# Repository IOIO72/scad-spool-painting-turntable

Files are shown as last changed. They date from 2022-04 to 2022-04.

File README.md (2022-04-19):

# scad-spool-painting-turntable
Spool Painting Turntable

**Update** (5 June 2021):

You can print test parts to verify your measurements of the diameters and inner ring height without wasting too much time and filament.

**Major update** (20 May 2021):

I have converted this model into a customizable version. From now on you can adjust the painting turntable to the individual size of your filament spool.

All you have to do is measure the diameter of the spool and the diameter of the spool hole. Just enter these values as basic parameters in the Customizer.

Please note that rendering in the Customizer takes some time. It is a bit faster if you use [OpenSCAD](https://openscad.org/) on your computer, but even there it takes some time.

If you don't use the Customizer, you can still download my original STL file for the small 200g spool.

**Original description:**

Included with my Creality CR10 printer was a **200g spool** of filament. The empty spool had been lying around unused for quite some time. So I decided to upcycle it and turned it into a painting turntable.

I use the turntable for my airbrush painting. If you want to attach the object you like to paint, just use double sided tape.

Since I don't know if the dimensions of the spool are common, here are my measurements: the inner diameter is about 52mm and the outer diameter is about 149mm. The height of the inner circle border is 5mm to hook up the table to the spool.

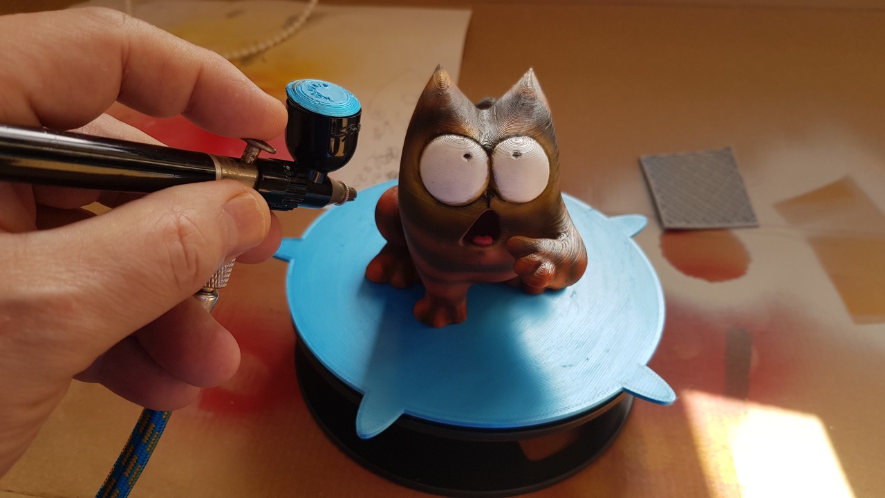
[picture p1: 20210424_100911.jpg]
Spool Painting Turntable

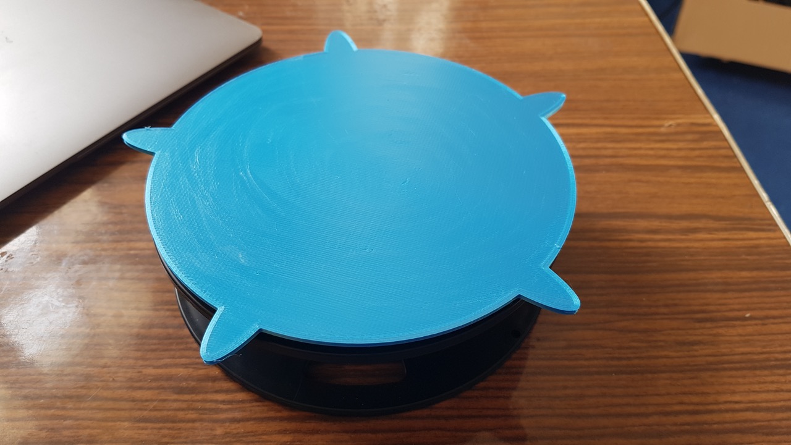
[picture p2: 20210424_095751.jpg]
Spool Painting Turntable empty

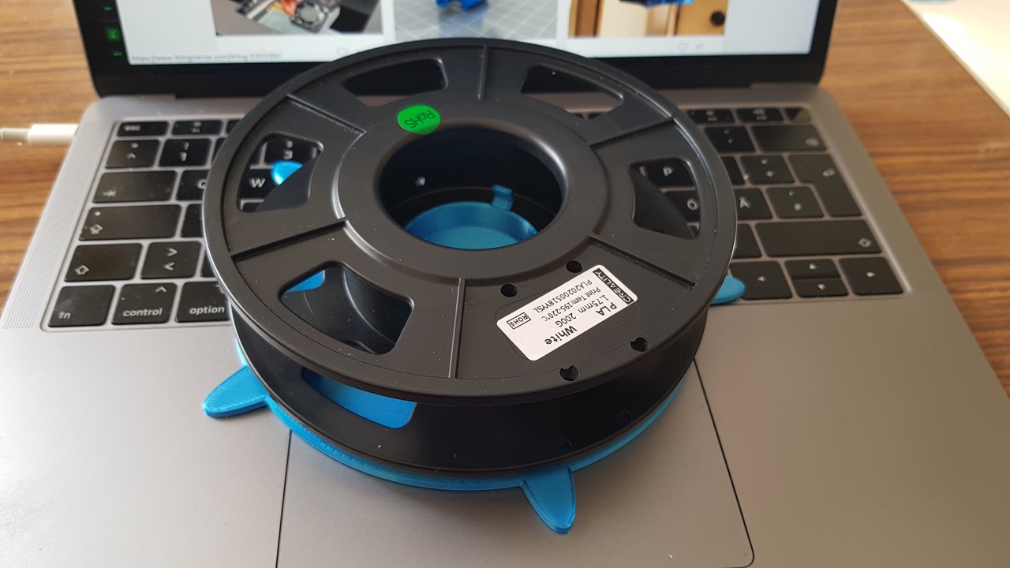
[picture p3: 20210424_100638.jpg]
Spool Painting Turntable bottom

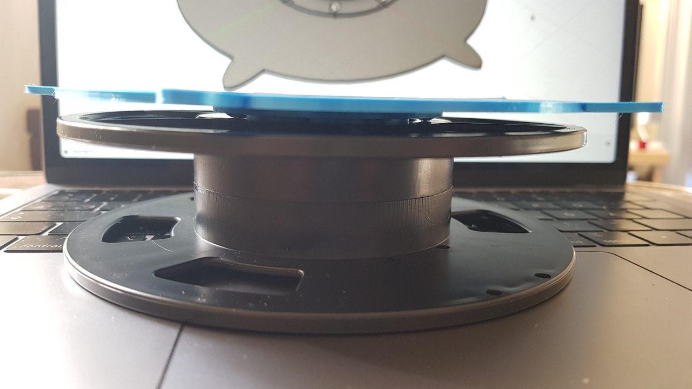
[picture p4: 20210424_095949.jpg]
Spool Painting Turntable side

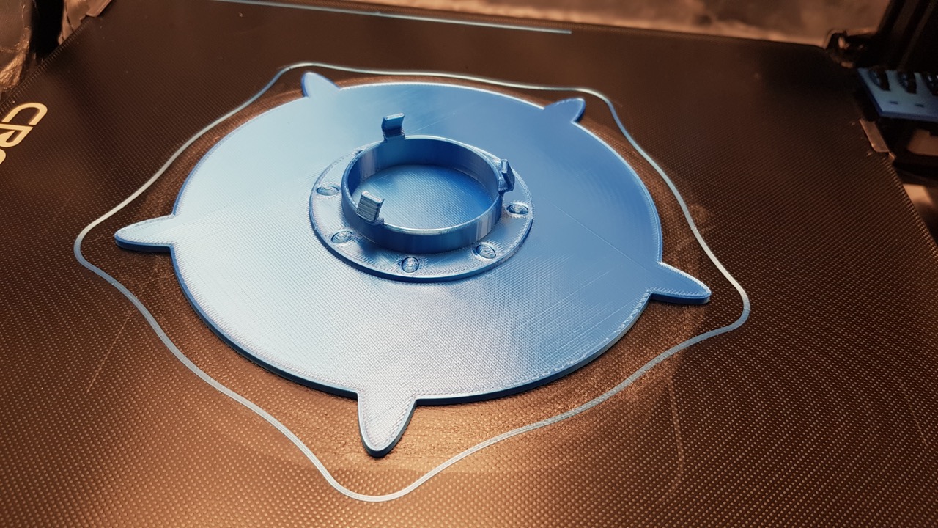
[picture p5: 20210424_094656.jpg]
Spool Painting Turntable Print


## Test Parts

You can print test parts to verify your measurements without wasting too much time and filament.

You may use the vase mode (aka "spiralize outer contour"), two walls and concentric bottom shell filling.

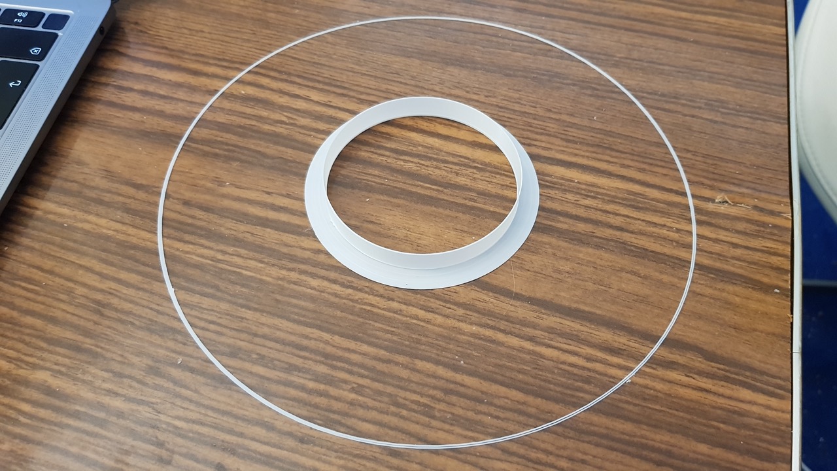
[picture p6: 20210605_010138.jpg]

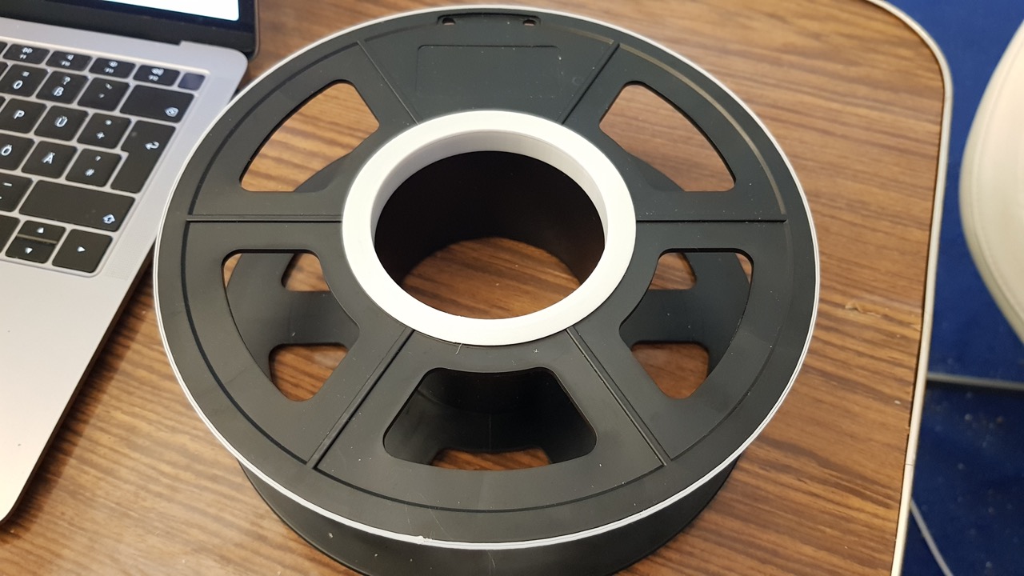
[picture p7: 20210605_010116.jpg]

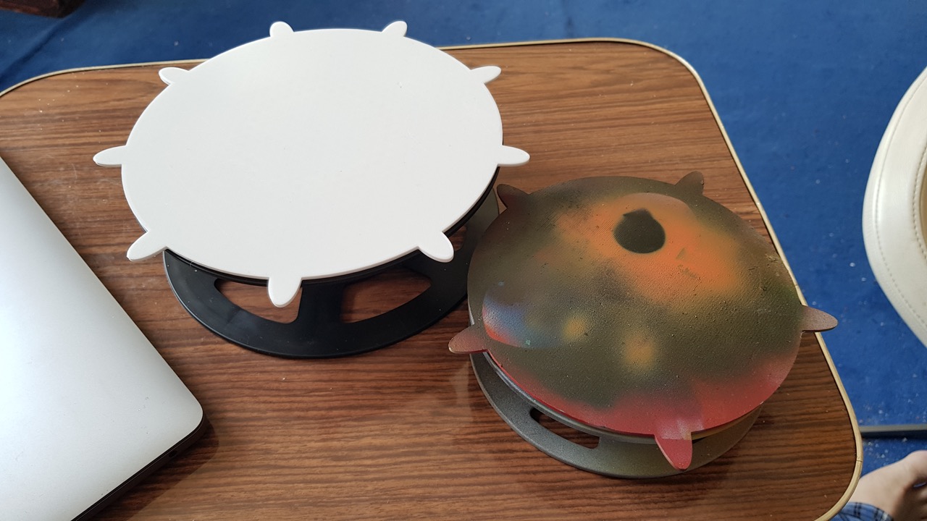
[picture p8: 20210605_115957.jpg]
Tested Parts


## Use OpenSCAD

1. **Download and install:** [OpenSCAD](http://openscad.org/) version 2021.01 or newer
2. **Download:** The *.scad file of this model.
3. **Start** OpenSCAD and **open** the *.scad file in it.
4. **Open the customizer** via the menu "Window/Customizer"

Now you can configure the model and use the `F5` key to render the preview of your changes.

### Export your STL file

If you're done with your model settings, you can export the STL file:

1. Render the mesh by pressing the `F6` key.
2. Wait until the rendering is finished. This might take some minutes.
3. Export the STL file by pressing the `F7` key.

### Optionally save your configuration

If you like to use your configuration as a template for further models, it's a good idea, to save your configuration:

1. Click the `+` symbol in the customizer, which you find beside the configuration selector drop-down in the second line of the customizer.
2. Give your configuration a name.

Use the drop-down menu to access your saved configurations.

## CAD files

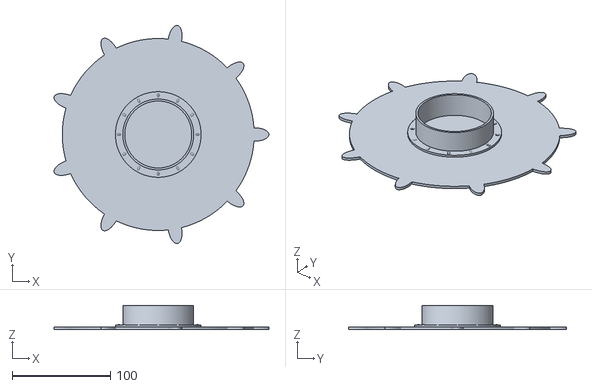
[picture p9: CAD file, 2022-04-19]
enotepad_spool_painting_turntable.stl
218.4 x 221.7 x 24.5

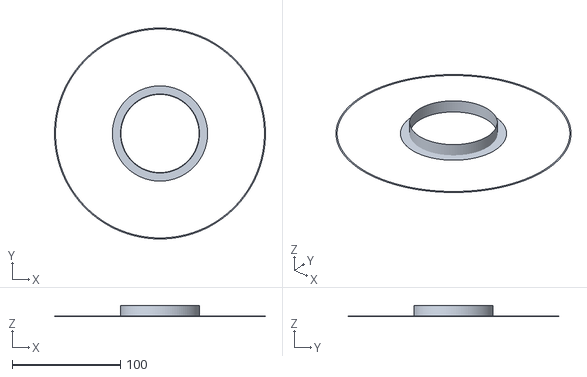
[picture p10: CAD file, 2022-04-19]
test_enotepad_spool_painting_turntable.stl
195.0 x 195.0 x 10.4

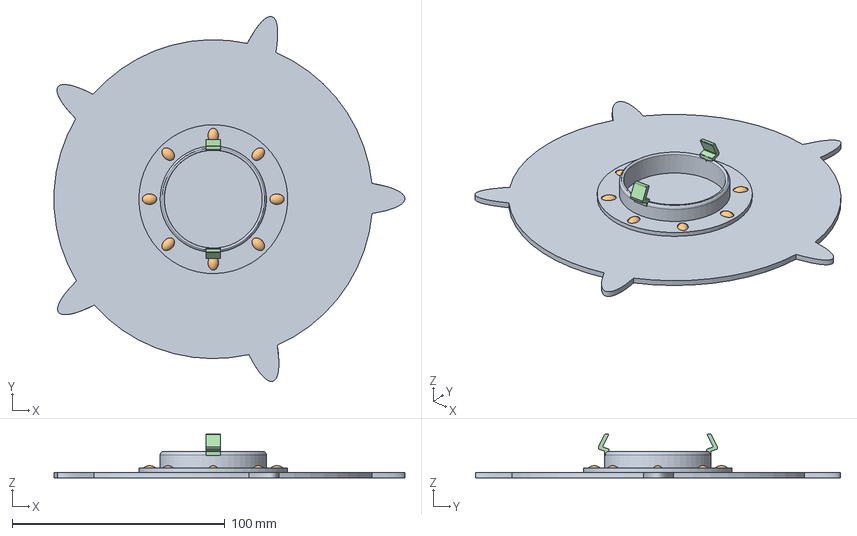
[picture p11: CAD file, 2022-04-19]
Spool Painting Turntable v16.step
165.0 x 171.7 x 20.5 mm

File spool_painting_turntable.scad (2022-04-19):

/*
  Parametric Spool Painting Turntable v0.6
  by IOIO72 aka Tamio Patrick Honma
  
  License: CC BY-NC-SA 4.0
  https://creativecommons.org/licenses/by-nc-sa/4.0/

  This is the parametric version of the original model for 200g filament spools:
  https://www.thingiverse.com/thing:4838023
*/


/* [Basic Parameters in millimeters] */

// The turntable diameter should equal the diameter of your spool
turntable_diameter = 150;

// The inner diameter of your spool, which is the spool's hole
spool_inner_diameter = 50;

// Print test parts to verify your measurements of the diameters and inner ring height
test_parts = false;


/* [Number of Elements] */

// Number of handles
handle_number = 5;

// Number of glide lentils
lentil_number = 8;

// Number of hooks to mount the turntable to the spool
hook_number = 2;



/* [Heights in millimeters] */

// The height of the inner ring, which goes into your spool's hole
spool_inner_height = 8;

// The height of the turntable, which is the plate itself
turntable_height = 2.5;


/* [Additional Parameters] */

// The size of the handles
handle_size = 30;

// The width of the glide ring, which contains the glide lentils
spool_glide_width = 20;

// Offset of the hook
hook_offset = 2;

// Height of the hook
hook_height = 8;

// Width of the hook
hook_width = 7;

// Test part inner ring wall size
test_wall = 0.8;

// Test part base height
test_height = 0.4;

// Number of fragments
$fn = 100; // [50:200]


/* [Hidden] */

wall_size = 2;


module ring(height,diameter,inner_diameter) {
  linear_extrude(height=height) {
    difference () {
      circle(d=diameter);
      circle(d=inner_diameter);
    };
  };
};

if (test_parts == false) {

  linear_extrude(turntable_height) {

    // Handles
    if (handle_number > 0) {
      for(n = [1 : handle_number]) {
        rotate(a=n * 360 / handle_number, v=[0, 0, 1])
        translate([turntable_diameter / 2, 0, 0])
        resize([handle_size, handle_size / 2.2])
        circle(d=100);
      };
    };

    // Turntable
    circle(d=turntable_diameter);
  };


  // Spool inner ring
  ring(spool_inner_height + turntable_height + wall_size, spool_inner_diameter, spool_inner_diameter - wall_size * 2);

  // Spool glide ring
  ring(turntable_height + wall_size, spool_inner_diameter + spool_glide_width, spool_inner_diameter);

  // Glide lentils
  if (lentil_number > 0) {
    for(n = [1 : lentil_number]) {
      rotate(a=n * 360 / lentil_number, v=[0, 0, 1])
      translate([0, (spool_inner_diameter / 2 + spool_glide_width / 4), turntable_height + wall_size / 2]) {
        difference() {
          resize([spool_glide_width / 5, spool_glide_width / 2 - wall_size, spool_glide_width / 5])
          sphere(d=spool_glide_width / 2);
          translate([0, 0, -spool_glide_width / 20])
          cube(size=[spool_glide_width / 5, spool_glide_width / 2 - wall_size, spool_glide_width / 10], center=true);
        }
      }
    };
  };

  // Hooks
  if (hook_number > 0) {
    for (n = [1 : hook_number]) {
      rotate(a=n * 360 / hook_number, v=[0, 0, 1])
      translate([0, spool_inner_diameter / 2, spool_inner_height + turntable_height + wall_size]) {
        rotate(a=270, v=[0, 1, 0])
        linear_extrude(hook_width, center=true)
        polygon([[0,-wall_size], [0,0], [1,hook_offset], [2,hook_offset], [hook_height,0], [hook_height, -wall_size], [2,hook_offset - wall_size], [1,-wall_size]]);
      };
    };
  };

} else {
  // Test Parts
  
  // Test Part for Spool inner ring
  ring(spool_inner_height + test_height, spool_inner_diameter, spool_inner_diameter - test_wall);

  // Test Part for Spool glide ring
  ring(test_height, spool_inner_diameter + spool_glide_width, spool_inner_diameter);

  // Test Part for Turntable
  ring(test_height, turntable_diameter, turntable_diameter - 2);

};

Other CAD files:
Spool Painting Turntable v16.f3d
Spool Painting Turntable v16.stl
